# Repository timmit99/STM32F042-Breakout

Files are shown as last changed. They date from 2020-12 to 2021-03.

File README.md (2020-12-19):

# STM32F042 Breakout #
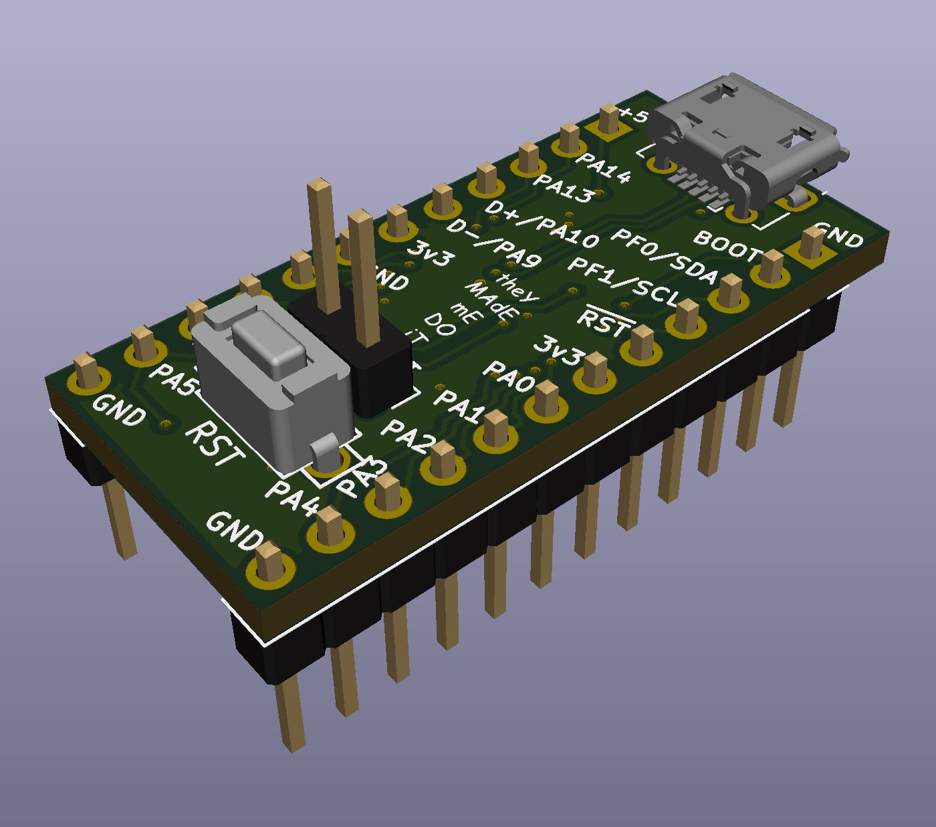
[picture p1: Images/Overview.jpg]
V-Naught_Display


[Interactive bom](http://htmlpreview.github.io/?https://github.com/timmit99/STM32F042-Breakout/blob/main/ibom.html)

## The board has: ##
 - STM32F042F6P6 MCU with internal oscillator
 - USB port
 - Reset button
 - All GPIO pins broken out
 - Silkscreen (kinda)
 - Power and PB1 LED

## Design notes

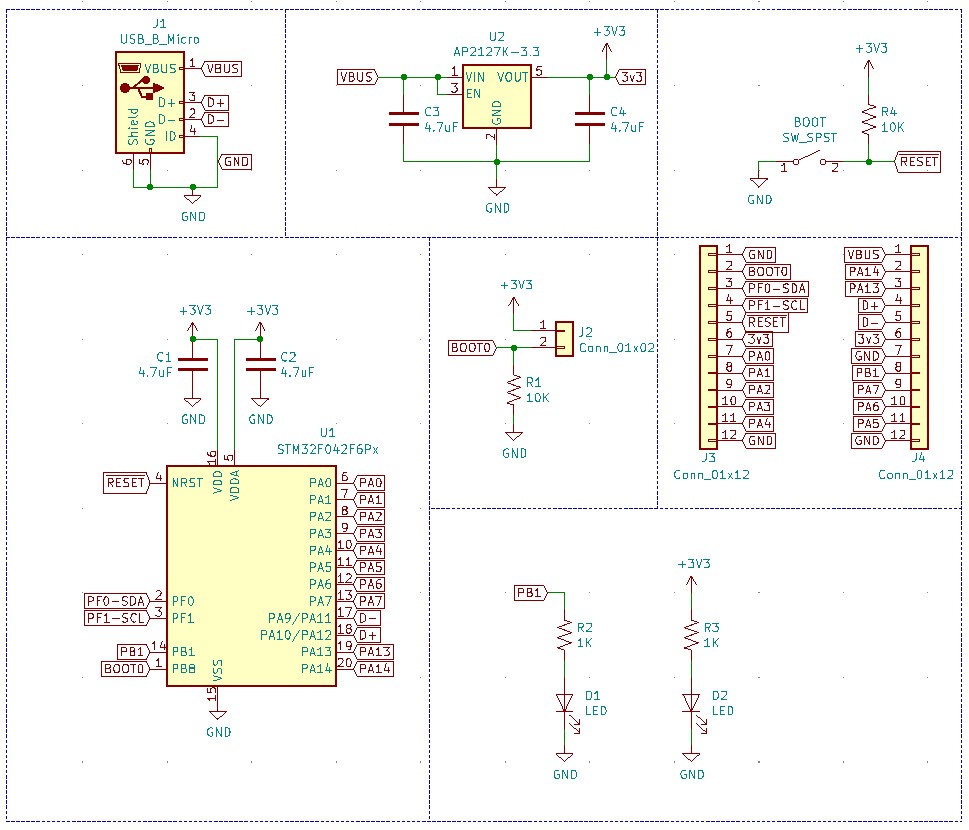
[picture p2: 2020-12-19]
Images/Schematic.jpg

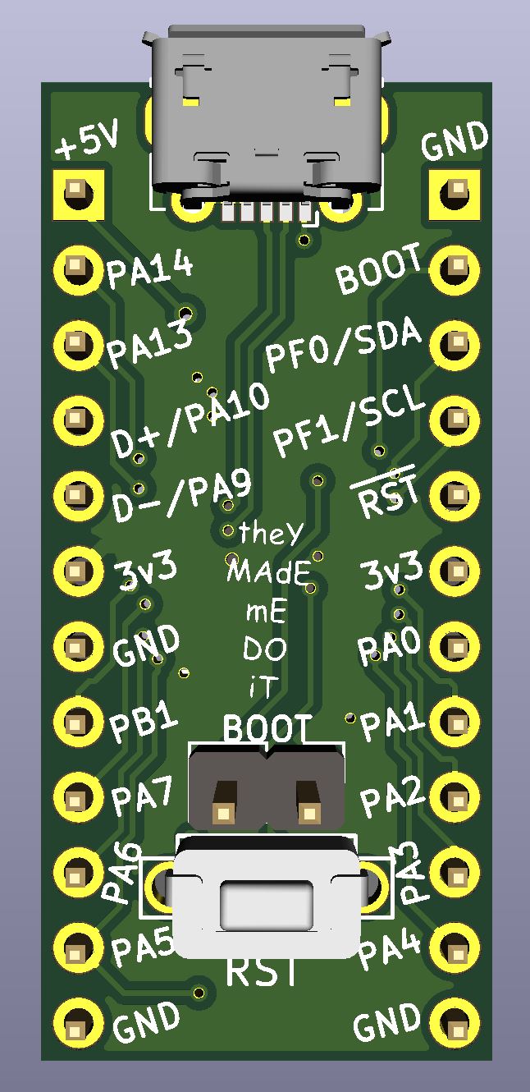
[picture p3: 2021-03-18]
Images/Top.jpg

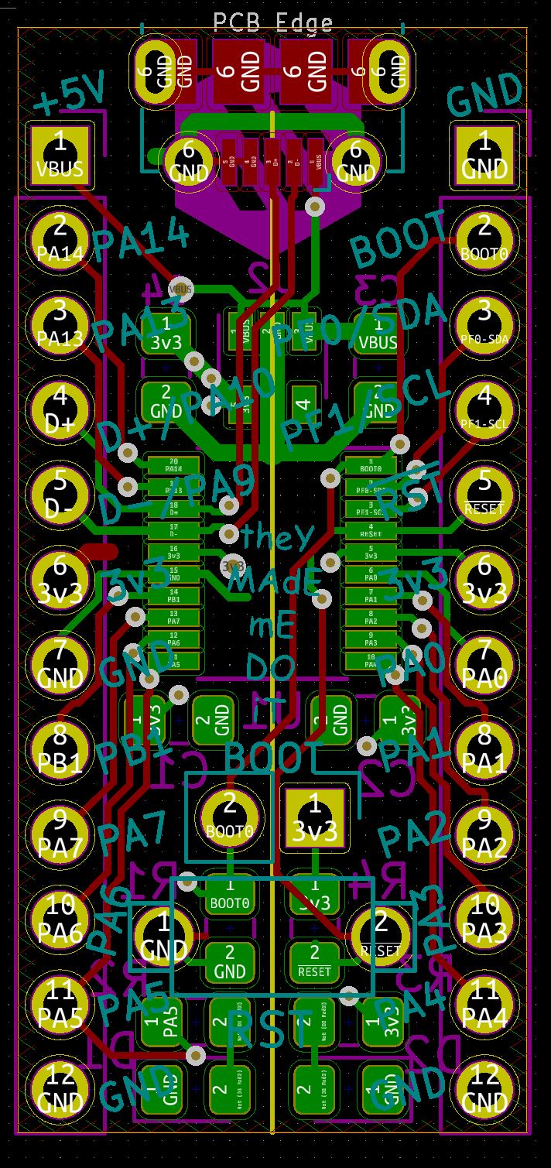
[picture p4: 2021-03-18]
Images/PCB.jpg

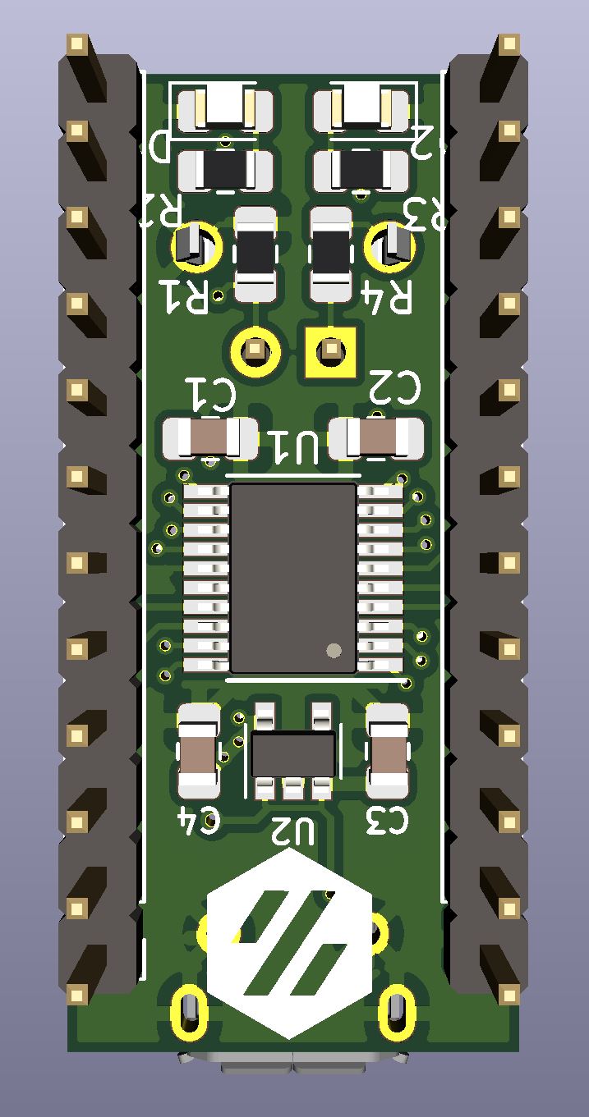
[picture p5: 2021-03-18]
Images/Bottom.jpg

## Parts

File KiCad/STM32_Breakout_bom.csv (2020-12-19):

Reference | Value | Footprint | Datasheet
U1 | STM32F042F6Px | Package_SO:TSSOP-20_4.4x6.5mm_P0.65mm | http://www.st.com/st-web-ui/static/active/en/resource/technical/document/datasheet/DM00105814.pdf
J1 | USB_B_Micro | STM32_Breakout:Molex-105017-0001-USBMicroB | ~
U2 | AP2127K-3.3 | Package_TO_SOT_SMD:SOT-23-5 | https://www.diodes.com/assets/Datasheets/AP2127.pdf
C3 | 4.7uF | Capacitor_SMD:C_0805_2012Metric_Pad1.15x1.40mm_HandSolder | ~
C4 | 4.7uF | Capacitor_SMD:C_0805_2012Metric_Pad1.15x1.40mm_HandSolder | ~
C1 | 4.7uF | Capacitor_SMD:C_0805_2012Metric_Pad1.15x1.40mm_HandSolder | ~
C2 | 4.7uF | Capacitor_SMD:C_0805_2012Metric_Pad1.15x1.40mm_HandSolder | ~
RST1 | SW_SPST | STM32_Breakout:2PinTactileButton | ~
R4 | 10K | Resistor_SMD:R_0805_2012Metric_Pad1.15x1.40mm_HandSolder | ~
J2 | Conn_01x02 | Connector_PinHeader_2.54mm:PinHeader_1x02_P2.54mm_Vertical | ~
R1 | 10K | Resistor_SMD:R_0805_2012Metric_Pad1.15x1.40mm_HandSolder | ~
D2 | LED | LED_SMD:LED_0805_2012Metric_Pad1.15x1.40mm_HandSolder | ~
R3 | 1K | Resistor_SMD:R_0805_2012Metric_Pad1.15x1.40mm_HandSolder | ~
D1 | LED | LED_SMD:LED_0805_2012Metric_Pad1.15x1.40mm_HandSolder | ~
R2 | 1K | Resistor_SMD:R_0805_2012Metric_Pad1.15x1.40mm_HandSolder | ~
J4 | Conn_01x12 | Connector_PinHeader_2.54mm:PinHeader_1x12_P2.54mm_Vertical | ~
J3 | Conn_01x12 | Connector_PinHeader_2.54mm:PinHeader_1x12_P2.54mm_Vertical | ~

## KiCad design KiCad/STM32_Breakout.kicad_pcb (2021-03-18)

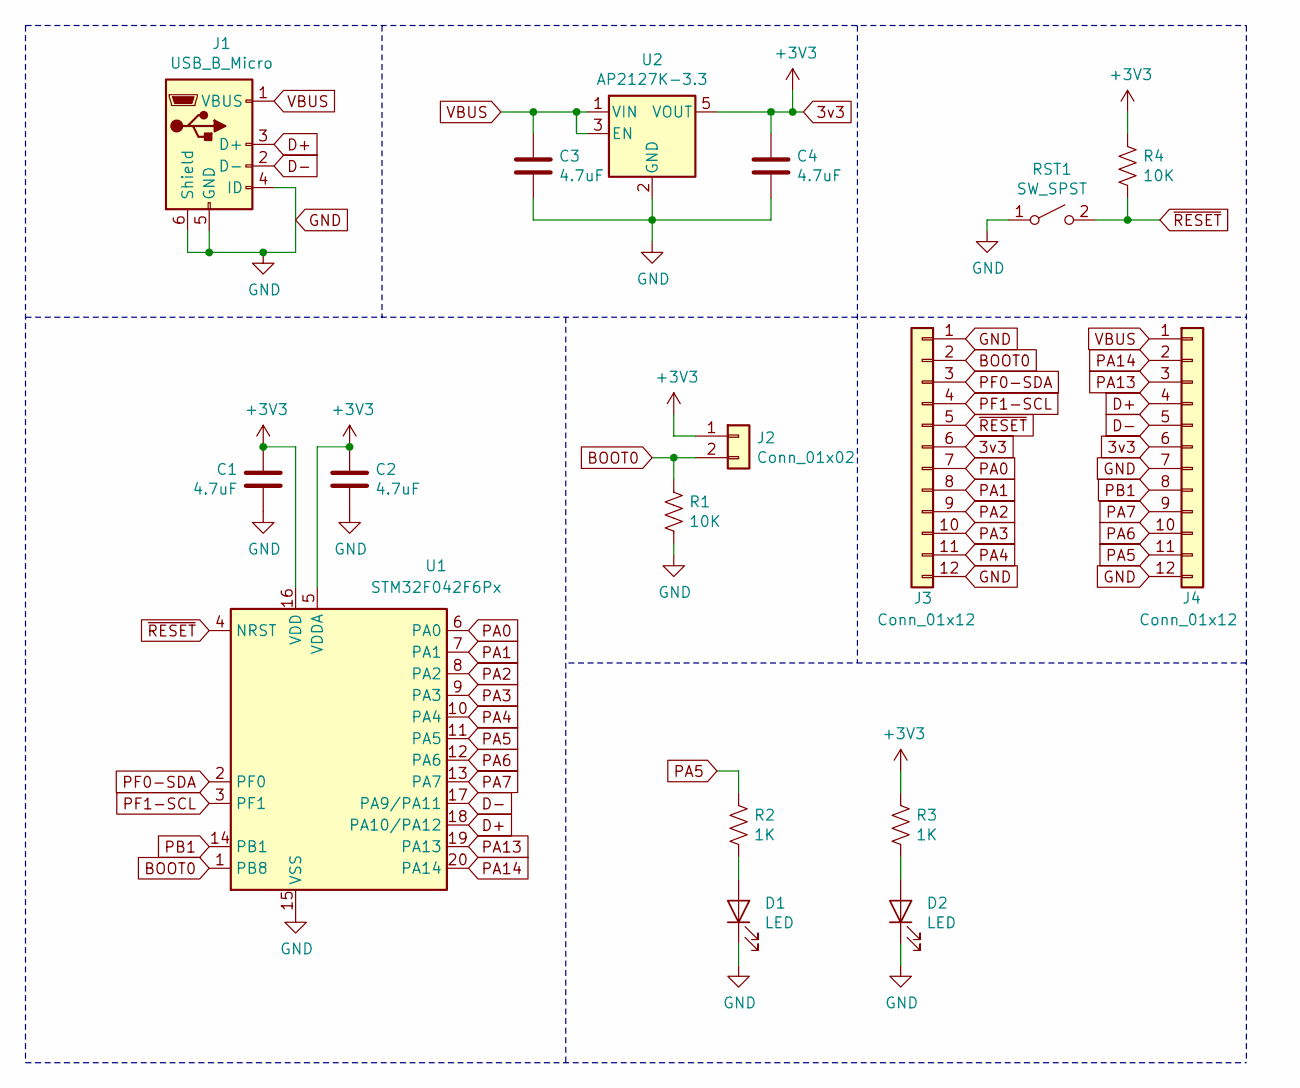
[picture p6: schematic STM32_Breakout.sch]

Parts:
C1, C2, C3, C4: 4.7uF; C_0805_2012Metric_Pad1.15x1.40mm_HandSolder
D1, D2: LED; LED_0805_2012Metric_Pad1.15x1.40mm_HandSolder
J1: USB_B_Micro; Molex-105017-0001-USBMicroB
J2: Conn_01x02; PinHeader_1x02_P2.54mm_Vertical
J3, J4: Conn_01x12; PinHeader_1x12_P2.54mm_Vertical
R1, R4: 10K; R_0805_2012Metric_Pad1.15x1.40mm_HandSolder
R2, R3: 1K; R_0805_2012Metric_Pad1.15x1.40mm_HandSolder
RST1: SW_SPST; 2PinTactileButton
U1: STM32F042F6Px; TSSOP-20_4.4x6.5mm_P0.65mm
U2: AP2127K-3.3; SOT-23-5

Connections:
3v3: C1.1, C2.1, C4.1, J2.1, J3.6, J4.6, R3.1, R4.1, U1.5 (VDDA), U1.16 (VDD), U2.5 (VOUT)
BOOT0: J2.2, J3.2, R1.1, U1.1 (PB8)
D+: J1.3 (D+), J4.4, U1.18 (PA10/PA12)
D-: J1.2 (D-), J4.5, U1.17 (PA9/PA11)
GND: C1.2, C2.2, C3.2, C4.2, D1.1 (K), D2.1 (K), J1.4 (ID), J1.5 (GND), J1.6 (Shield), J3.1, J3.12, J4.7, J4.12, R1.2, RST1.1 (A), U1.15 (VSS), U2.2 (GND); also elsewhere on the board
unnamed: D1.2 (A), R2.2
unnamed: D2.2 (A), R3.2
PA0: J3.7, U1.6 (PA0)
PA1: J3.8, U1.7 (PA1)
PA2: J3.9, U1.8 (PA2)
PA3: J3.10, U1.9 (PA3)
PA4: J3.11, U1.10 (PA4)
PA5: J4.11, R2.1, U1.11 (PA5)
PA6: J4.10, U1.12 (PA6)
PA7: J4.9, U1.13 (PA7)
PA13: J4.3, U1.19 (PA13)
PA14: J4.2, U1.20 (PA14)
PB1: J4.8, U1.14 (PB1)
PF0-SDA: J3.3, U1.2 (PF0)
PF1-SCL: J3.4, U1.3 (PF1)
VBUS: C3.1, J1.1 (VBUS), J4.1, U2.1 (VIN), U2.3 (EN)
~RESET: J3.5, R4.2, RST1.2 (B), U1.4 (NRST); also elsewhere on the board

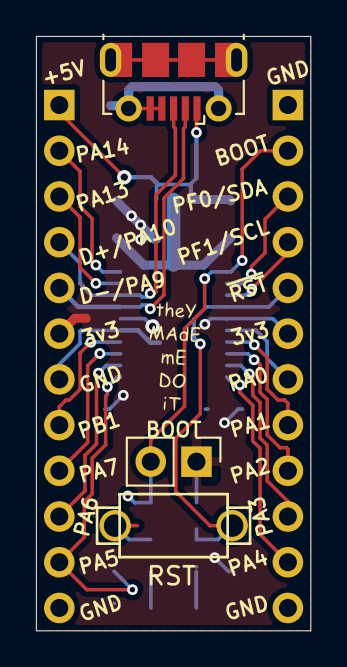
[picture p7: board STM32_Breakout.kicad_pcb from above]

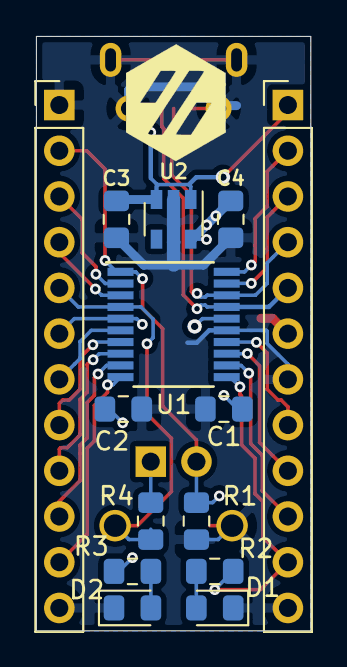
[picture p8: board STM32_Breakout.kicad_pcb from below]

Board: 2 copper layers, 15.2 x 33.0 mm, 17 parts (14 on the bottom side), 22 nets.

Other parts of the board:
RST: SW_SPST; 2PinTactileButton

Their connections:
GND: RST.1; also elsewhere on the board
~RESET: RST.2; also elsewhere on the board

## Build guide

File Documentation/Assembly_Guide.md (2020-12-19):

## V0 Display Assembly Guide: ##

This is **NOT** an instruction manual. While the components here were picked as they were easy to solder with an iron it is not an "easy/beginner" project.
 
----
### Assembly Guide
- For initial testing install:
    - MCU (U2)
	- MCU Caps (C3,C4)
	- Voltage Regulator (U1)
	- Regulator Caps (C1, C2)
	- USB port (If you are using it), or USB header
	
- Verify there are no shorts between 5V and ground (On the USB header) as well as 3V and ground (Across C2).
	- If there are shorts, examine the components for solder bridges and recheck.
	- If there are no shorts, continue.

- Plug board into Pi and follow the [Setup guide](Setup_and_Flashing_Guide.md) until step 5 to verify that the MCU is operational and detected.

- Finish the SMD assembly by installing the:
	- Neopixel buffer (U3)
	- Other resistors (R1-R3)
	- Neopixel (On front of board)

- Install Headers:
	- Boot Jumper (J4)
	- OpenOCD (J3)
	- *optional* GPIO (GPIO)
	- *optional* USB (J7)
	- *optional* Neopixel Data Out(J8)
	
- Install encoder or 4 tactile switches for navigation
- Install 6mm x 6mm x 4.3mm for Kill Switch (SW6) and Reset Switch (SW5)
	-Needs to be 4.3mm tall for the stock button lever to work.
	
- Finally, install the 1.3" OLED screen with the printed spacer under the bottom to keep it flat.
	- *NOTE* once this is installed it is difficult to access other parts without removing the display,

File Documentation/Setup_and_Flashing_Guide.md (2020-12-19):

## V0 Display Flashing Instructions:

1) Connect the board to the host Raspberry Pi via USB.
2) This step depends on if your board has firmware on it or not already:

	a) If you have a pre-flashed board:
		-Install the boot jumper and reset the board. This will put the board into DFU mode.
	
	b) If you have an unflashed board:
		- The MCU default's to DFU mode if there is no other firmware installed.
		
	 - confirm the board enters DFU mode in step 4
	
3) Connect to your host raspberry pi via SSH
4) Run `lsusb` from the command prompt
	- Make sure you see an STM32 in DFU mode listed
5) Run `dfu-util --list` from the command prompt
	- note the text inside the [xxxx:yyyy]
6) Run `CD ~/klipper` from the command line to enter the Klipper directory
7) Run `make menuconfig` settings should be:

	- [\*] Enable extra low-level configuration options 
 
	- Micro-controller Architecture (STMicroelectronics STM32)

	- Processor model (STM32F042)

	- Clock Reference (Internal clock)

	- [\*] Use USB for communication (instead of serial)

	- [\*] Use PA9/PA10 for USB or CAN

	- USB ids  --->[ ] Specify a custom step pulse duration

	- ( )  GPIO pins to set at micro-controller startup 
	
	Exit and Save
8) Run `make clean` to clean up the make environment.
9) Run `make flash FLASH_DEVICE=xxxx:yyyy` (using xxxx:yyyy from above)
10) After completion `ls /dev/serial/by-id/*` should return a device begining with `/dev/serial/by-id/usb-Klipper_stm32f042x6...`

Your board should now be usable with Klipper. Use the example config files to get started
Best optioon is to copty the config you want to use into the same directory as `printer.cfg` then add `[include NAME_OF_CONFIG.CFG]` to the end of your `printer.cfg` to include the file.

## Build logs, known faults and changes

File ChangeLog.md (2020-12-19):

# Change Log #

## Rev A:
 - Initial Release

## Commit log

2020-12-19 Initial release
    Initial release of STM32F042 dev board.
    Has VERY limited (i.e. crappy) silkscreen so use at own risk.
    [STM32_Breakout.kicad_pcb, STM32_Breakout.sch]
2020-12-19 Update for additional... something
    Added silkscreen labels, moved SMD parts to bottom,
2020-12-19 Gerber addition
    [STM32_Breakout-B_Cu.gbr, STM32_Breakout-B_Mask.gbr, STM32_Breakout-B_Paste.gbr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]
2021-03-18 Patch 002 (#1)
    * add ignore
    * Clean up ignored files
    * save unsaved changes
    * Update pin
    [STM32_Breakout-B_Cu.gbr, STM32_Breakout-B_Mask.gbr, STM32_Breakout-B_Paste.gbr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]
